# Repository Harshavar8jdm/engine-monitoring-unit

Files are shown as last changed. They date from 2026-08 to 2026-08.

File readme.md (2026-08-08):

# Engine Monitoring Unit (EMU) 🏍️⚡







An open-source, automotive-grade **Engine Monitoring Unit (EMU)** designed to bring real-time engine telemetry and diagnostics to air-cooled single-cylinder motorcycles (such as the Hero Passion Plus) that lack factory instrumentation.

Powered by an **STM32F411CEU6** ARM Cortex-M4 microcontroller, this unit captures vital thermal, electrical, and rotational parameters and displays them on a handlebar-mounted OLED screen—giving riders full visibility over engine health during long highway cruises and touring trips.

---

## 📌 Gallery

| Top 3D Render | Bottom 3D Render |
| :---: | :---: |
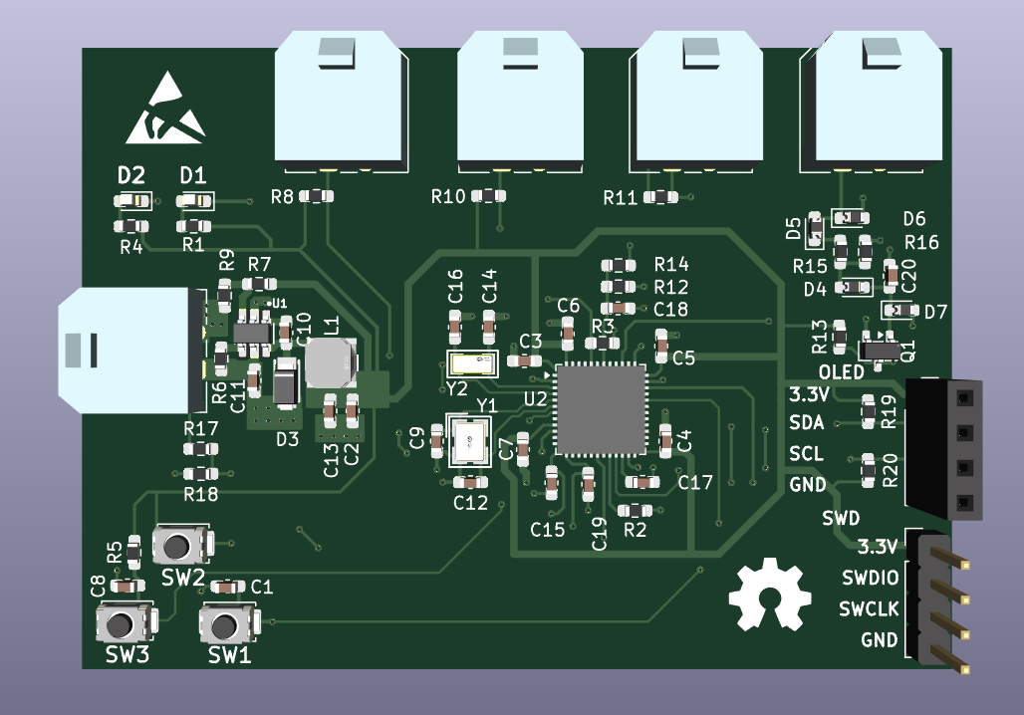
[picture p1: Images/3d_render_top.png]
Top 3D Render
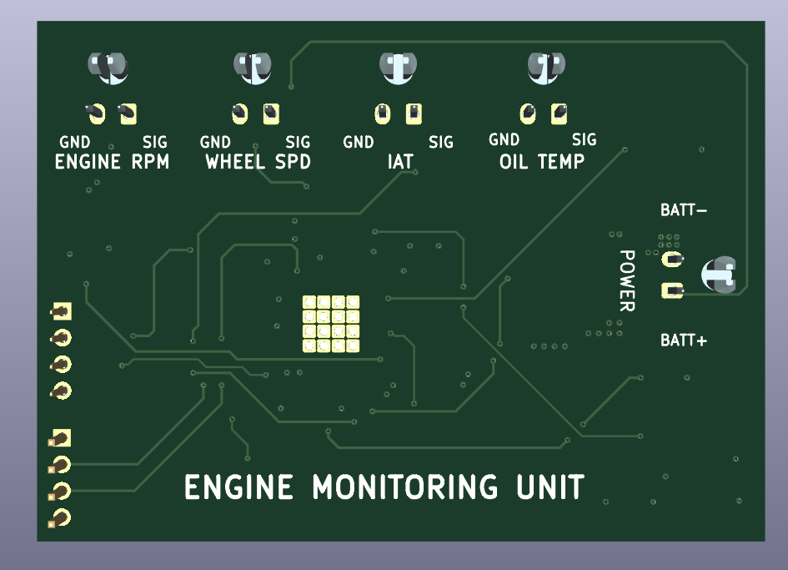
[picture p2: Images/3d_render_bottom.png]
Bottom 3D Render
|  |  |

---

## 🎯 Motivation & Objectives

Stock commuter motorcycles often lack essential monitoring tools, providing only a basic speedometer and fuel gauge. When pushing small-displacement air-cooled engines on long rides or steep climbs, thermal overload or electrical failure can happen without warning.

This project solves that real-world problem by providing:
1. **Real-time Engine Health Visibility:** Monitoring oil temperature and intake air temperature (IAT) to prevent overheating.
2. **Electrical System Telemetry:** Tracking live battery voltage to monitor stator and regulator/rectifier performance.
3. **Engine Dynamics:** Accurate engine RPM via inductive pulse pickup and wheel speed tracking.
4. **Automotive EMI Immunity:** Designed specifically for high noise/vibration motorcycle chassis environments.
5. **Zero Parasitic Battery Drain:** Tied directly to switched ignition (+12V)—completely powered down when the key is OFF.

---

## 🛠️ Key Technical Specifications

| Parameter | Specification | Description |
| :--- | :--- | :--- |
| **Microcontroller** | STM32F411CEU6 | 100 MHz ARM Cortex-M4, 512KB Flash, 128KB SRAM |
| **Operating Voltage** | 12V DC nominal (Switched) | Powered directly from motorcycle ignition bus |
| **On-board Power** | LMR16006 Buck Converter | 12V → 3.3V Step-down (60V Max $V_{IN}$) |
| **Current Draw** | < 0.6A Operating | 0A Off-state (Zero parasitic load) |
| **PCB Stackup** | 4-Layer | Top (Sig/Pwr) - GND - GND - Bottom (Sig) |
| **Connectors** | Molex Micro-Fit 3.0 | Positive-locking, high-vibration automotive rating |
| **Display Interface** | 0.96" I2C OLED | 4-pin header (3.3V, SDA, SCL, GND) |
| **Debug Interface** | SWD | 4-pin header (3.3V, SWDIO, SWCLK, GND) |

---

## 📐 System Architecture & Schematic Overview

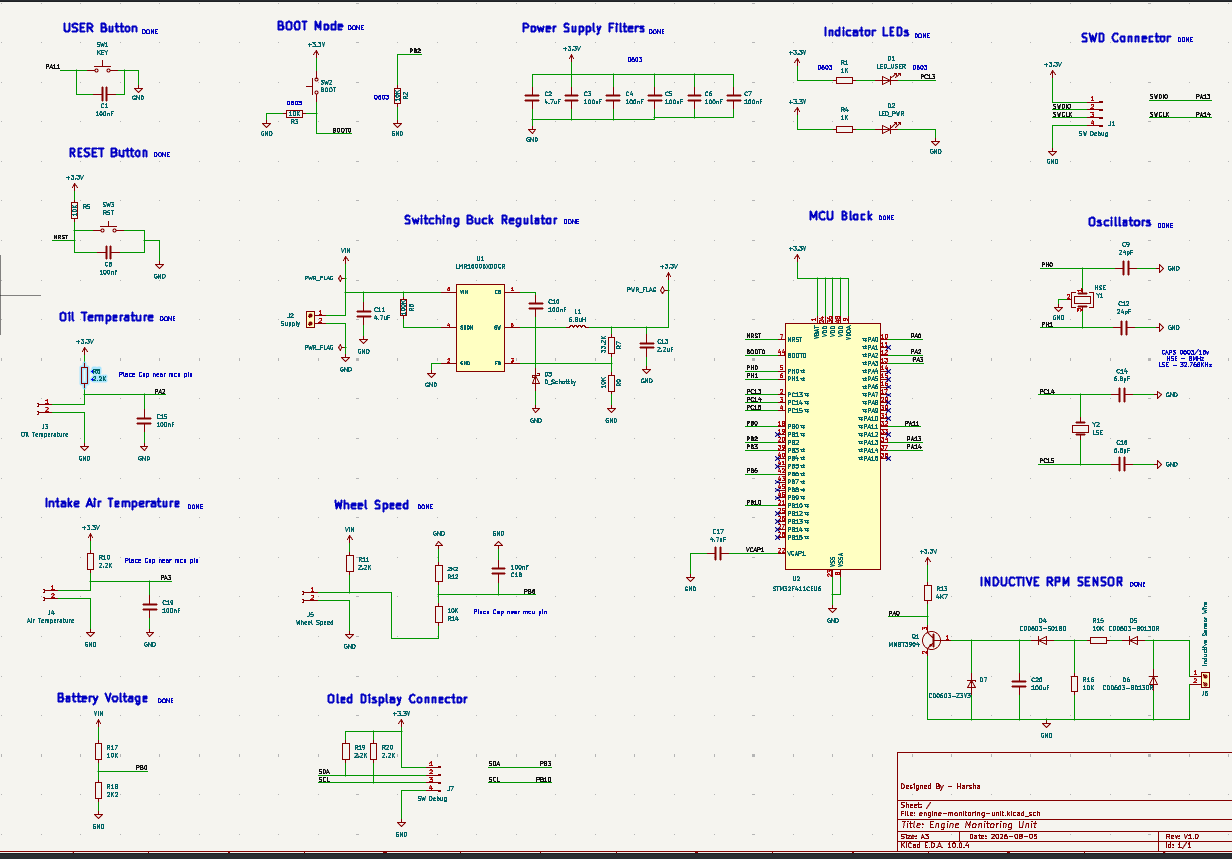
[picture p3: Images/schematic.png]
Full Schematic


### Circuit Block Summary:
* **Power Supply:** Uses a high-efficiency **LMR16006** synchronous buck regulator stepping down battery voltage to $+3.3\text{V}$ for the MCU and OLED display.
* **Microcontroller Core:** Minimalist STM32F411 layout with external $8\text{ MHz}$ HSE crystal ($Y_1$) and $32.768\text{ kHz}$ LSE crystal ($Y_2$), full decoupling capacitor network ($C_2 - C_7$), and pull-up/down logic for BOOT0/NRST.
* **Inductive RPM Conditioning:** Discrete NPN transistor ($Q_1$) amplifier stage paired with high-speed clamping diodes ($D_4 - D_7$) to cleanly condition high-voltage spark-plug coil inductive pulses into a 3.3V digital square wave.
* **Analog Sensor Inputs:** Resistive voltage dividers and $100\text{ nF}$ filtering capacitors for Oil Temp ($J_3$), Intake Air Temp ($J_4$), and Battery Voltage sensing ($J_2$).
* **Wheel Speed Conditioning:** Digital pulse input circuit with pull-up and low-pass filtering for hall-effect or reed switch wheel sensors ($J_5$).

---

## 📑 PCB Stackup & Layer Breakdown

To withstand the severe Electromagnetic Interference (EMI) generated by motorcycle ignition coils and spark plugs, the PCB utilizes a dedicated **4-layer stackup** with dual continuous internal ground planes.

```text
┌─────────────────────────────────────────────────────────┐
│ Layer 1: Top Layer (FCU)    -> Signals + 3.3V Power     │
├─────────────────────────────────────────────────────────┤
│ Layer 2: Inner 1 (In1)      -> Solid Ground Plane (GND) │
├─────────────────────────────────────────────────────────┤
│ Layer 3: Inner 2 (In2)      -> Solid Ground Plane (GND) │
├─────────────────────────────────────────────────────────┤
│ Layer 4: Bottom Layer (BCU) -> Signal Routing           │
└─────────────────────────────────────────────────────────┘

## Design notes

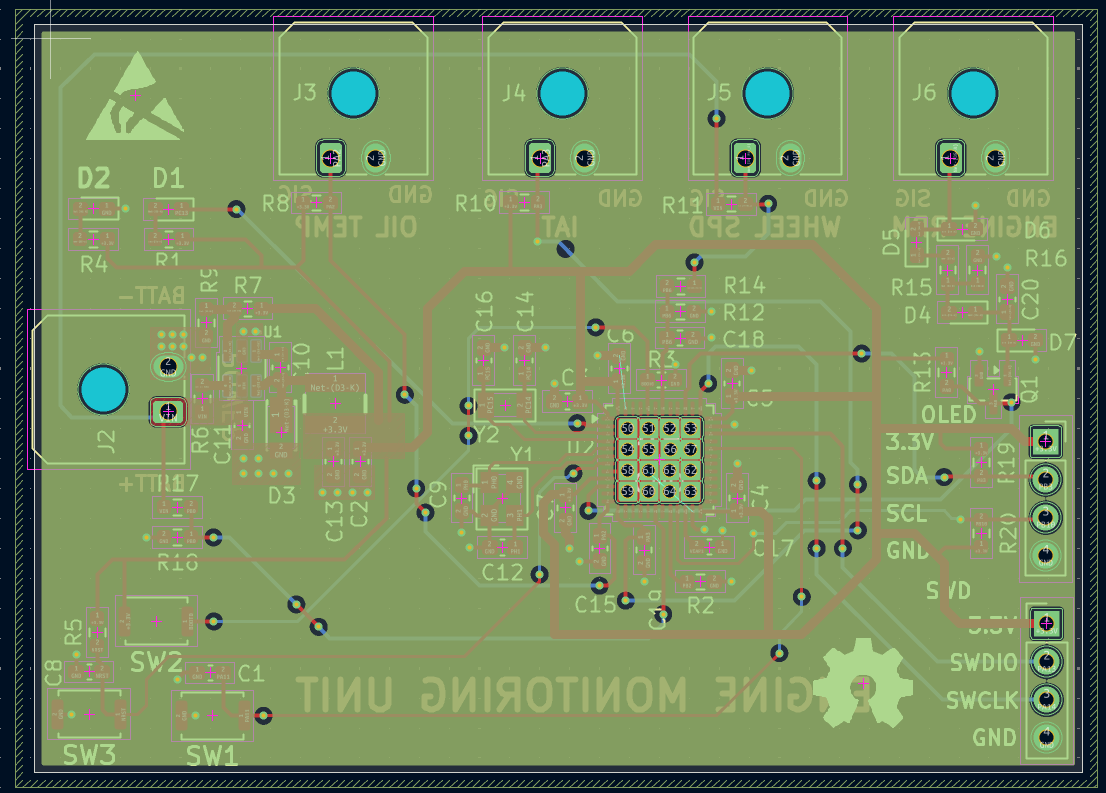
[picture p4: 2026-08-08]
Images/pcb_layout_in1.png

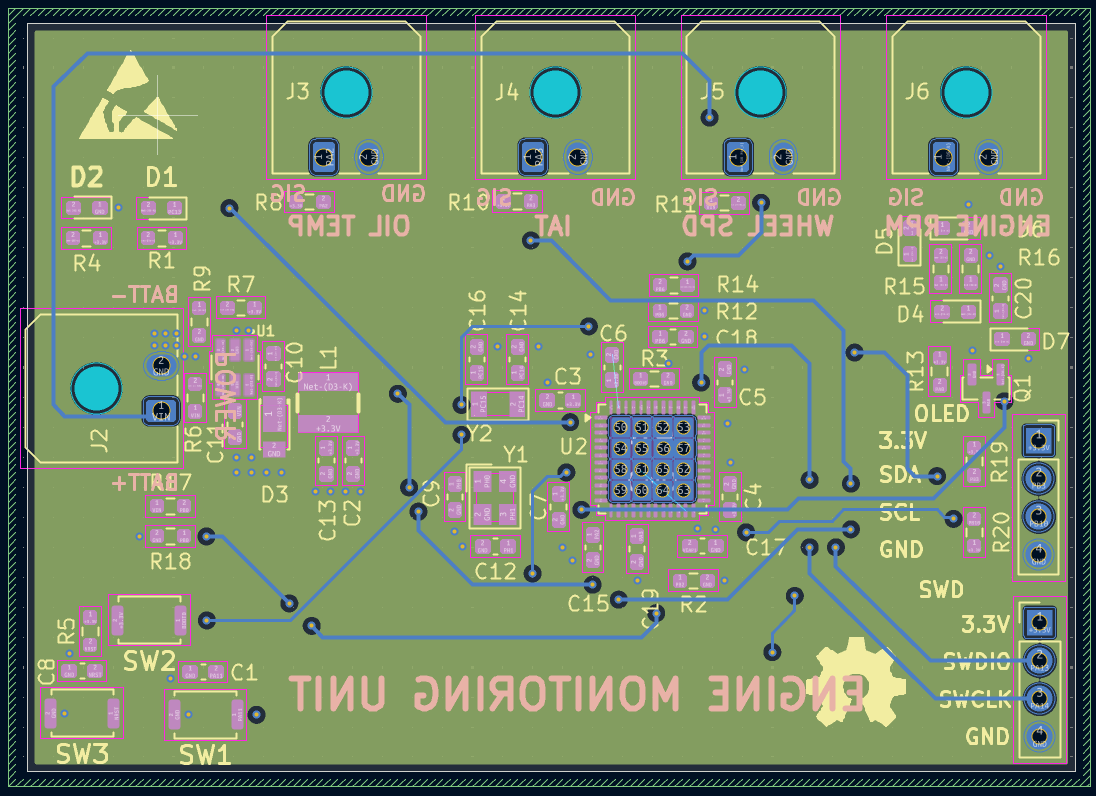
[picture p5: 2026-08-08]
Images/pcb_layout_bcu.png

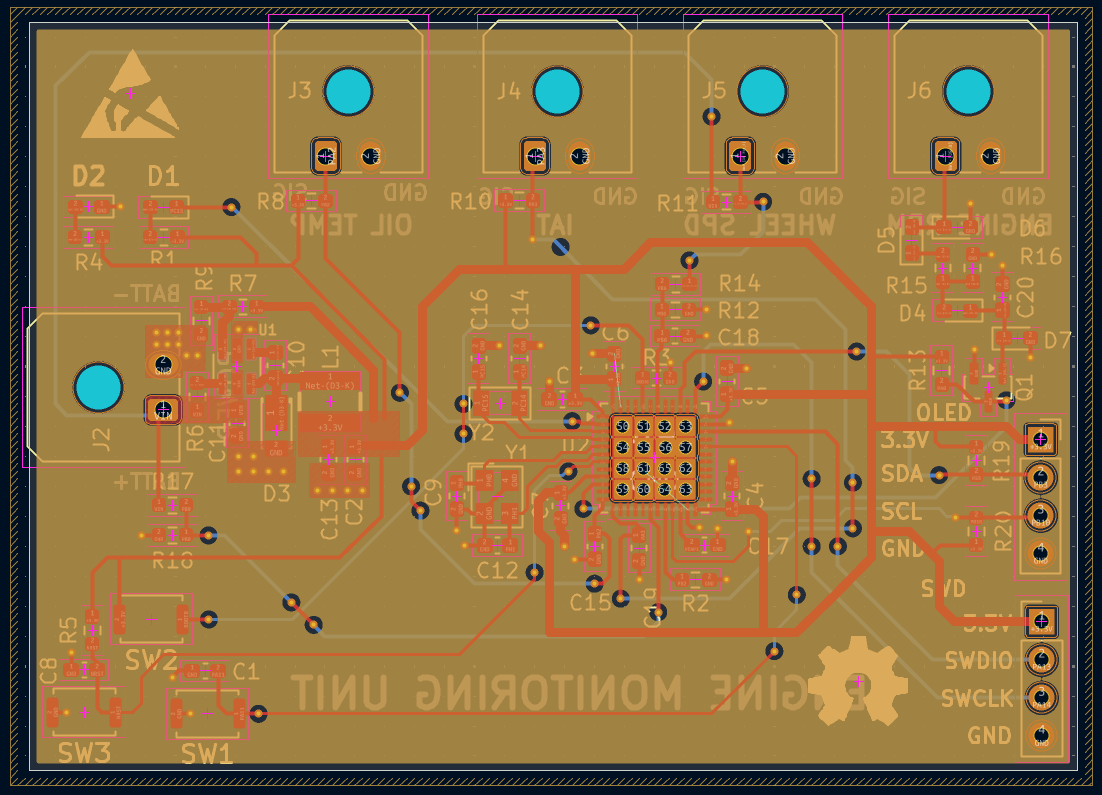
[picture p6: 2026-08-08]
Images/pcb_layout_in2.png

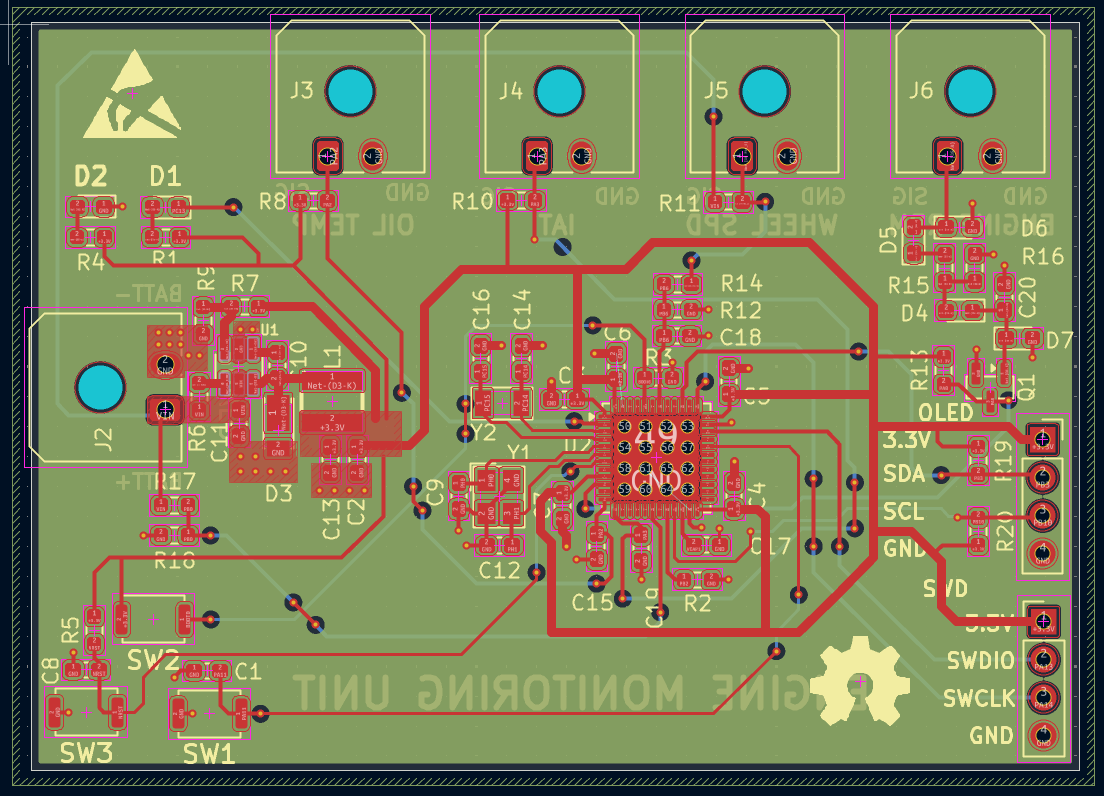
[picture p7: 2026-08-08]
Images/pcb_layout_fcu.png

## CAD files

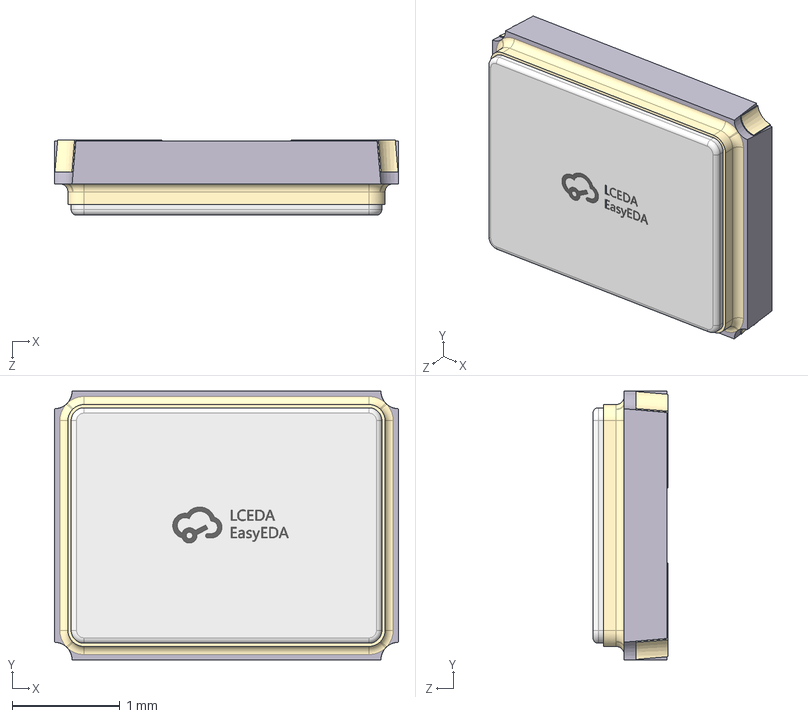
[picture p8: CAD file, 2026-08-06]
ext-libs/hse/CRYSTAL-SMD_4P-L3_2-W2_5-BL_0132M4-8_000F16DTNJL_C19674293/CRYSTAL-SMD_4P-L3_2-W2_5-BL_0132M4-8_000F16DTNJL_C19674293.step
3.20 x 2.50 x 0.701 mm

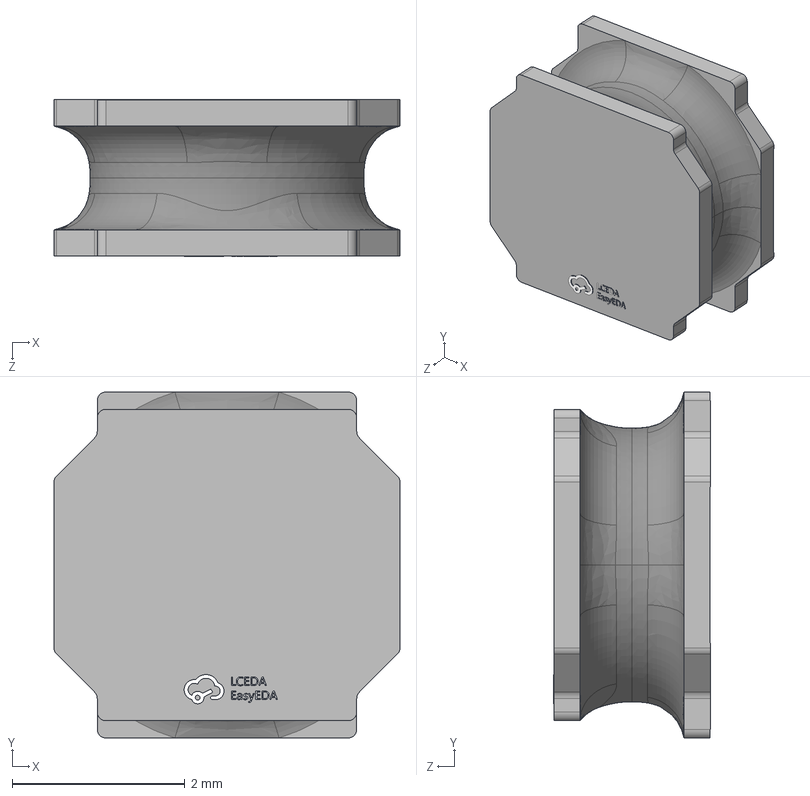
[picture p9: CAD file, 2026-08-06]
ext-libs/Inductor-6.8uH/IND-SMD_L4_0-W4_0_NRS4018T_NRS4018T6R8MDGJ_C222881.step
4.00 x 4.00 x 1.82 mm

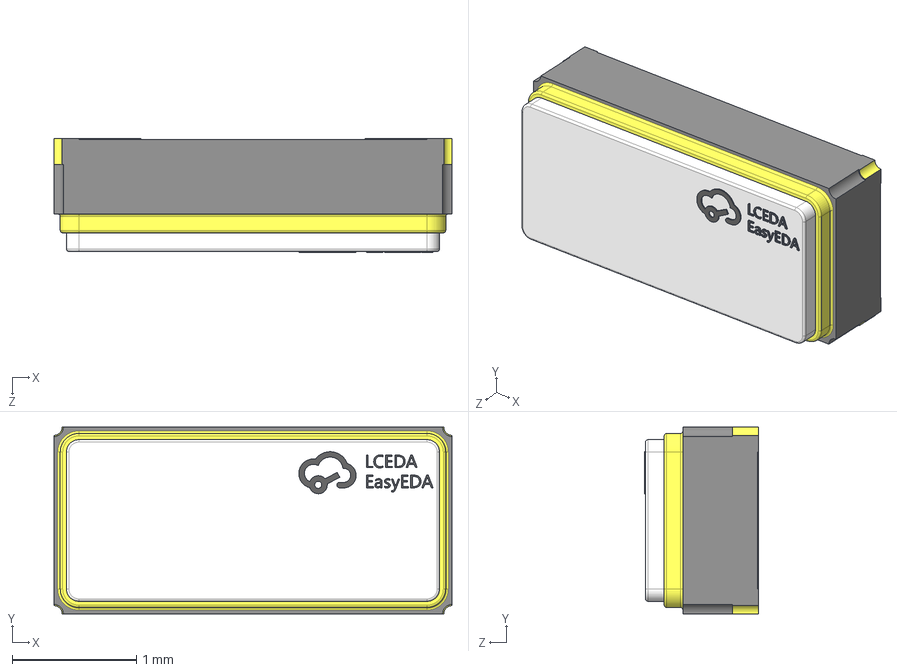
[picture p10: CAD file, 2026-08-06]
ext-libs/lse/CRYSTAL-SMD_L3_2-W1_5-1_3131M32768DT06LL_C5221300.step
3.20 x 1.50 x 0.92 mm

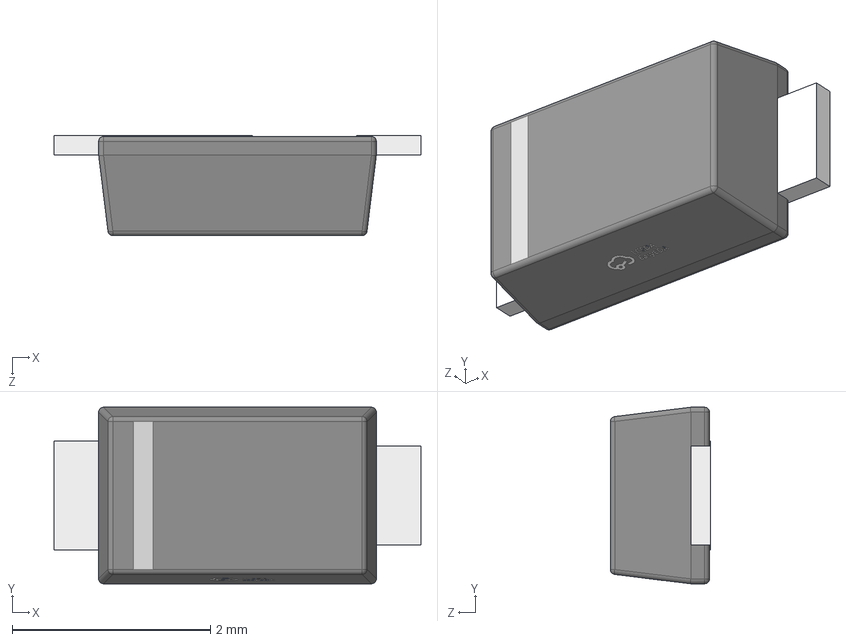
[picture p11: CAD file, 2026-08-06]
ext-libs/Schottky/POWERDI-123_L2_8-W1_8-LS3_7-RD-1_SS14FP_C894423.step
3.70 x 1.78 x 1.01 mm

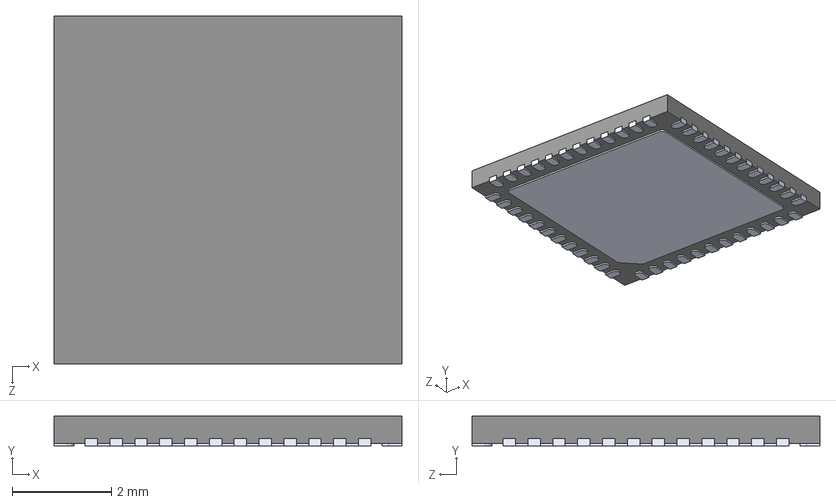
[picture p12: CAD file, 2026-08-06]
ext-libs/STM32F411CEU6/STM32F411CEU6TR.STEP
7.00 x 0.6 x 7.00 mm

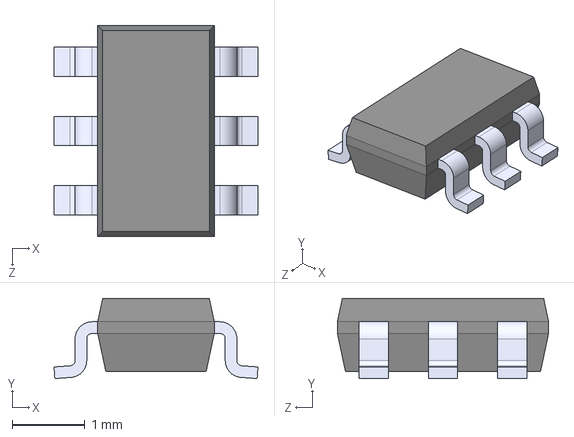
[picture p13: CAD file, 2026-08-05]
ext-libs/LMR16006XDDCR/LMR16006XDDCR.step
2.80 x 1.10 x 2.90 mm

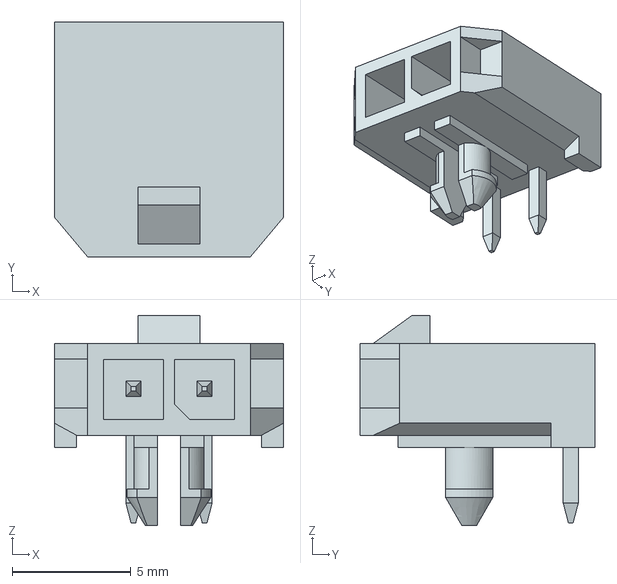
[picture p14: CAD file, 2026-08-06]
ext-libs/MOLEX_Micro-Fit-3-2P/436500200.stp
9.65 x 9.90 x 8.87 mm

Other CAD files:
ext-libs/Inductor-6.8uH/IND-SMD_L4_0-W4_0_NRS4018T_NRS4018T6R8MDGJ_C222881.obj
ext-libs/Schottky/POWERDI-123_L2_8-W1_8-LS3_7-RD-1_SS14FP_C894423.obj
ext-libs/hse/CRYSTAL-SMD_4P-L3_2-W2_5-BL_0132M4-8_000F16DTNJL_C19674293/CRYSTAL-SMD_4P-L3_2-W2_5-BL_0132M4-8_000F16DTNJL_C19674293.obj
ext-libs/lse/CRYSTAL-SMD_L3_2-W1_5-1_3131M32768DT06LL_C5221300.obj

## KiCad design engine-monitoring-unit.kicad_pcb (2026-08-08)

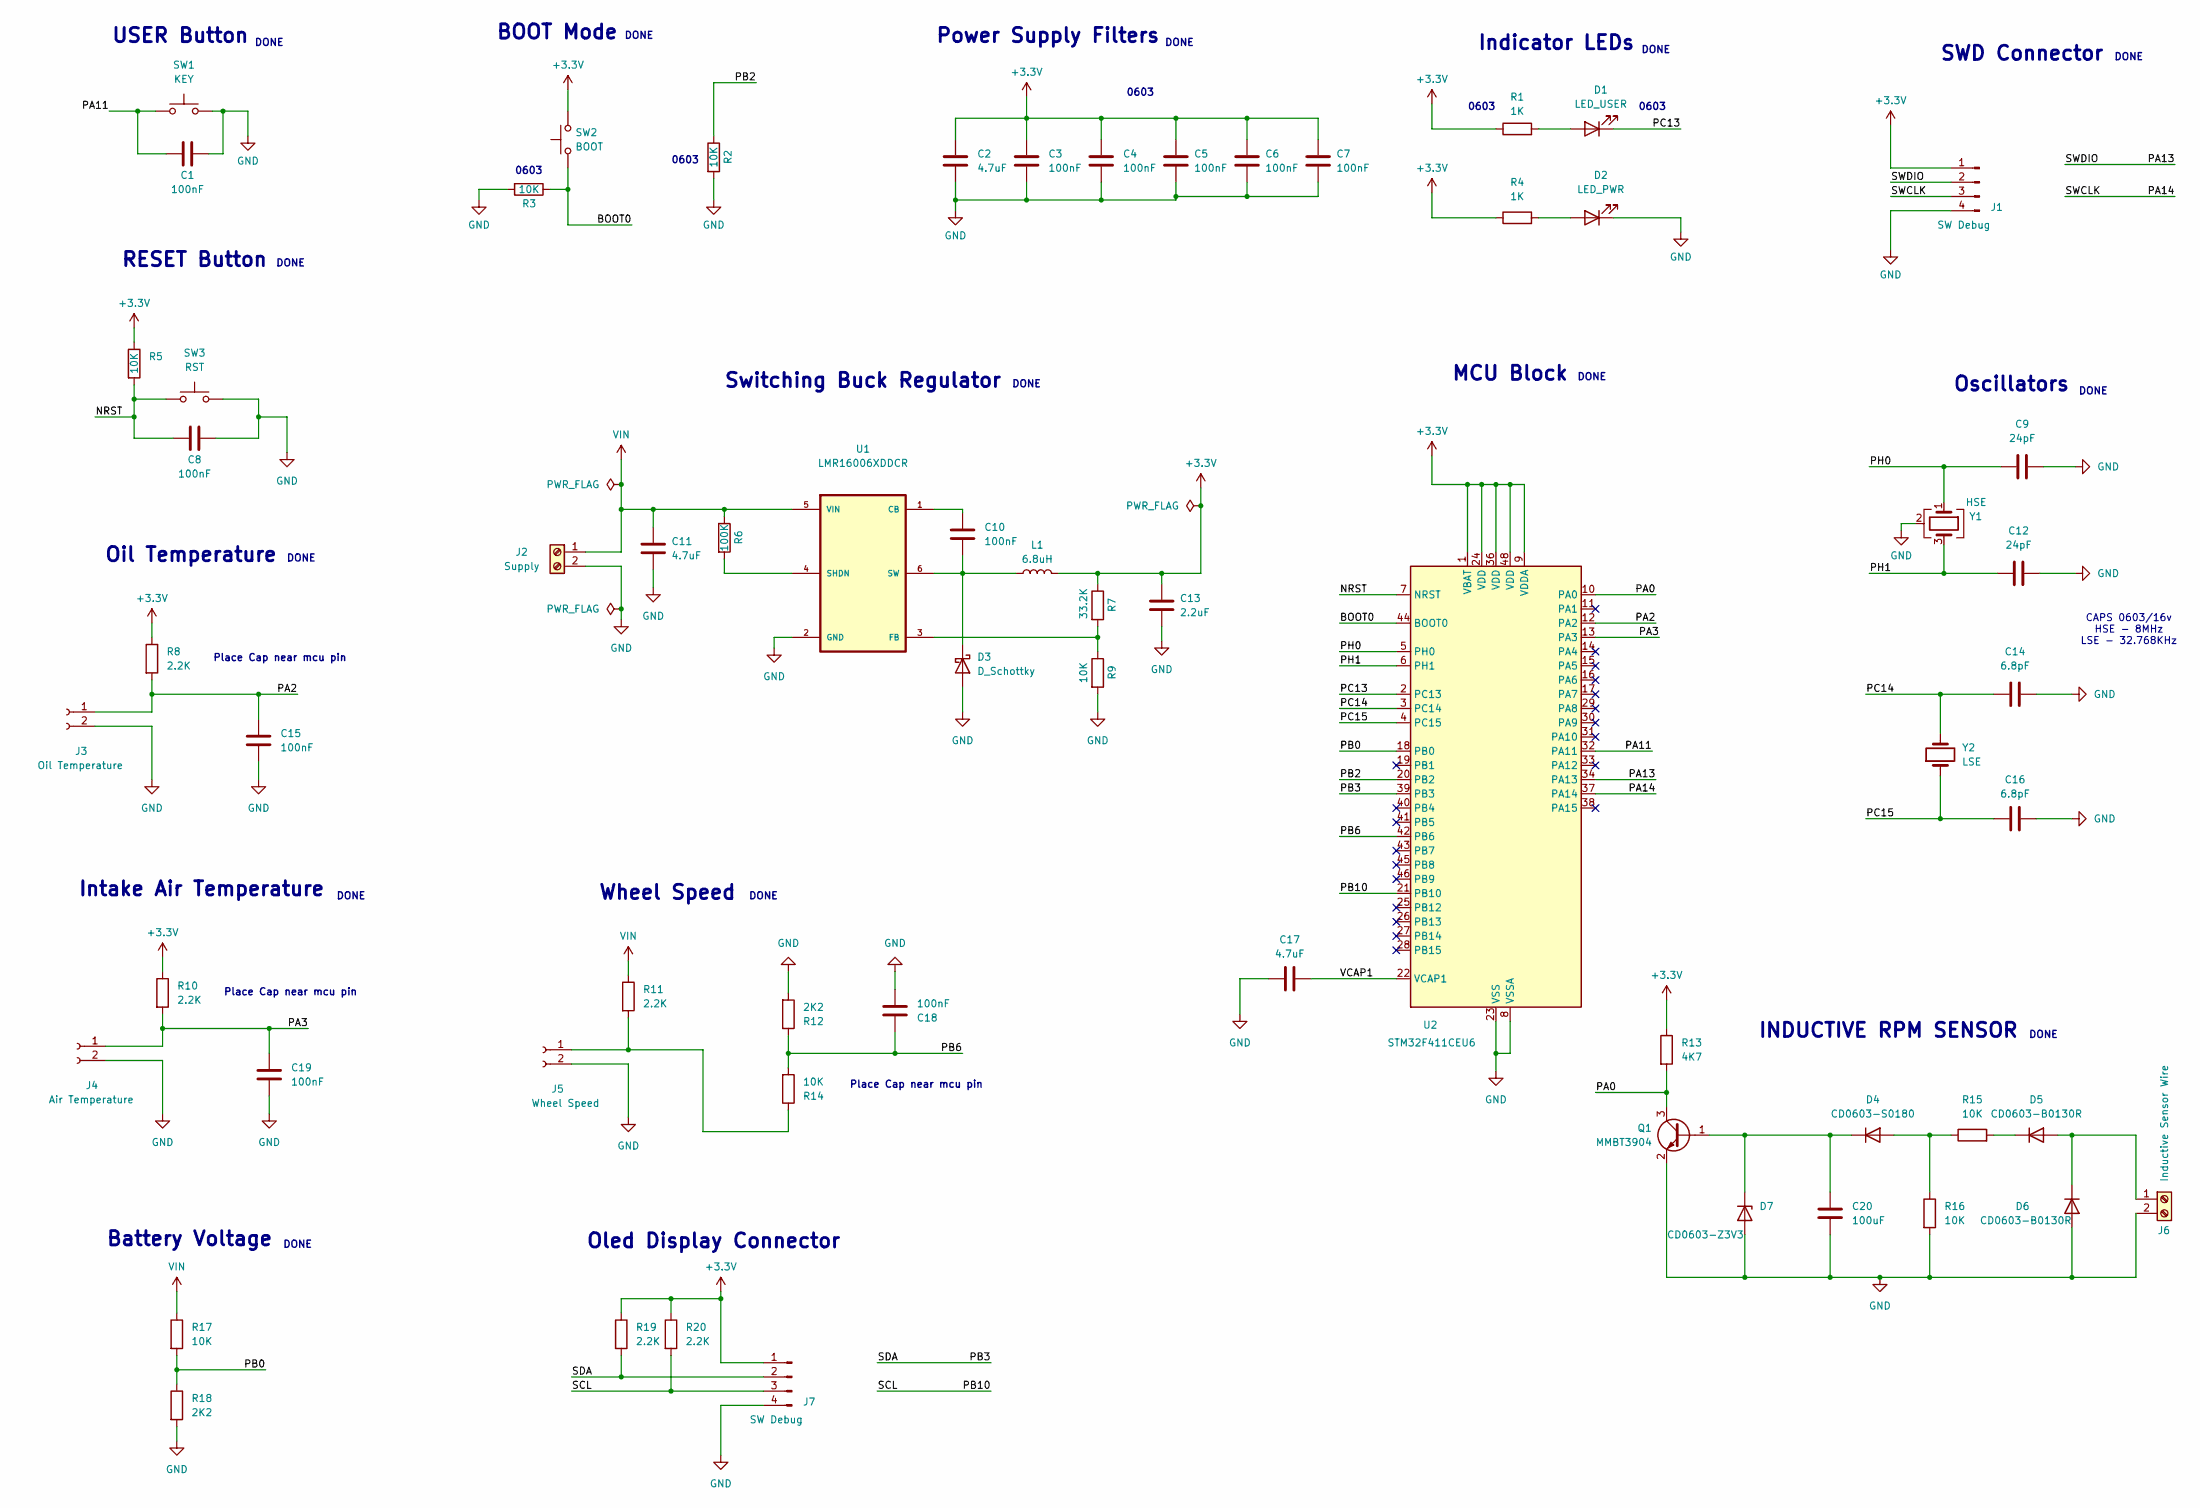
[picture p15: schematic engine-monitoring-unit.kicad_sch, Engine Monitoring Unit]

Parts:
C1, C3, C4, C5, C6, C7, C8, C10, C15, C18, C19: 100nF; C_0603_1608Metric_Pad1.08x0.95mm_HandSolder
C2, C11, C17: 4.7uF; C_0603_1608Metric_Pad1.08x0.95mm_HandSolder
C9, C12: 24pF; C_0603_1608Metric_Pad1.08x0.95mm_HandSolder
C13: 2.2uF; C_0603_1608Metric_Pad1.08x0.95mm_HandSolder
C14, C16: 6.8pF; C_0603_1608Metric_Pad1.08x0.95mm_HandSolder
C20: 100uF; C_0603_1608Metric_Pad1.08x0.95mm_HandSolder
D1: LED_USER; LED_0603_1608Metric_Pad1.05x0.95mm_HandSolder
D2: LED_PWR; LED_0603_1608Metric_Pad1.05x0.95mm_HandSolder
D3: D_Schottky; POWERDI-123_L2_8-W1_8-LS3_7-RD-1_SS14FP_C894423
D4: CD0603-S0180; D_0603_1608Metric_Pad1.05x0.95mm_HandSolder
D5, D6: CD0603-B0130R; D_0603_1608Metric_Pad1.05x0.95mm_HandSolder
D7: CD0603-Z3V3; D_0603_1608Metric_Pad1.05x0.95mm_HandSolder
J1: SW Debug; PinHeader_1x04_P2.54mm_Vertical
J2: Supply; Molex_Micro-Fit_3.0_43650-0200_1x02_P3.00mm_Horizontal
J3: Oil Temperature; Molex_Micro-Fit_3.0_43650-0200_1x02_P3.00mm_Horizontal
J4: Air Temperature; Molex_Micro-Fit_3.0_43650-0200_1x02_P3.00mm_Horizontal
J5: Wheel Speed; Molex_Micro-Fit_3.0_43650-0200_1x02_P3.00mm_Horizontal
J6: Inductive Sensor Wire; Molex_Micro-Fit_3.0_43650-0200_1x02_P3.00mm_Horizontal
J7: SW Debug; PinSocket_1x04_P2.54mm_Vertical
L1: 6.8uH; IND-SMD_L4_0-W4_0_NRS4018T_NRS4018T6R8MDGJ_C222881
Q1: MMBT3904; SOT-23
R1, R4: 1K; R_0603_1608Metric_Pad0.98x0.95mm_HandSolder
R2, R3, R5, R9, R14, R15, R16, R17: 10K; R_0603_1608Metric_Pad0.98x0.95mm_HandSolder
R6: 100K; R_0603_1608Metric_Pad0.98x0.95mm_HandSolder
R7: 33.2K; R_0603_1608Metric_Pad0.98x0.95mm_HandSolder
R8, R10, R11, R19, R20: 2.2K; R_0603_1608Metric_Pad0.98x0.95mm_HandSolder
R12, R18: 2K2; R_0603_1608Metric_Pad0.98x0.95mm_HandSolder
R13: 4K7; R_0603_1608Metric_Pad0.98x0.95mm_HandSolder
SW1: KEY; SW_Push_SPST_NO_Alps_SKRK
SW2: BOOT; SW_Push_SPST_NO_Alps_SKRK
SW3: RST; SW_Push_SPST_NO_Alps_SKRK
U1: LMR16006XDDCR; SOT95P280X110-6N
U2: STM32F411CEU6; QFN-48-1EP_7x7mm_P0.5mm_EP5.6x5.6mm
Y1: HSE; CRYSTAL-SMD_4P-L3_2-W2_5-BL_0132M4-8_000F16DTNJL_C19674293
Y2: LSE; CRYSTAL-SMD_L3_2-W1_5-1_3131M32768DT06LL_C5221300

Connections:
+3.3V: C2.1, C3.1, C4.1, C5.1, C6.1, C7.1, C13.1, J1.1, J7.1, L1.2, R1.1, R4.1, R5.1, R7.1, R8.1, R10.1, R13.1, R19.1, R20.1, SW2.2, U2.1 (VBAT), U2.9 (VDDA), U2.24 (VDD), U2.36 (VDD), U2.48 (VDD)
/BOOT0: R3.1, SW2.1, U2.44 (BOOT0)
/NRST: C8.2, R5.2, SW3.1, U2.7 (NRST)
/PA0: Q1.3 (C), R13.2, U2.10 (PA0)
/PA2: C15.1, J3.1, R8.2, U2.12 (PA2)
/PA3: C19.1, J4.1, R10.2, U2.13 (PA3)
/PA11: C1.2, SW1.1, U2.32 (PA11)
/PA13: J1.2, U2.34 (PA13)
/PA14: J1.3, U2.37 (PA14)
/PB0: R17.2, R18.1, U2.18 (PB0)
/PB2: R2.1, U2.20 (PB2)
/PB3: J7.2, R19.2, U2.39 (PB3)
/PB6: C18.1, R12.1, R14.2, U2.42 (PB6)
/PB10: J7.3, R20.2, U2.21 (PB10)
/PC13: D1.1 (K), U2.2 (PC13)
/PC14: C14.1, U2.3 (PC14), Y2.2
/PC15: C16.1, U2.4 (PC15), Y2.1
/PH0: C9.1, U2.5 (PH0), Y1.1
/PH1: C12.1, U2.6 (PH1), Y1.3
/VCAP1: C17.2, U2.22 (VCAP1)
GND: C1.1, C2.2, C3.2, C4.2, C5.2, C6.2, C7.2, C8.1, C9.2, C11.2, C12.2, C13.2, C14.2, C15.2, C16.2, C17.1, C18.2, C19.2, C20.2, D2.1 (K), D3.2 (A), D6.2 (A), D7.2 (A), J1.4, J2.2, J3.2, J4.2, J5.2, J6.2, J7.4, Q1.2 (E), R2.2, R3.2, R9.2, R12.2, R16.2, R18.2, SW1.2, SW3.2, U1.2 (GND), U2.8 (VSSA), U2.23 (VSS), U2.35 (VSS), U2.47 (VSS), U2.49 (VSS), Y1.2 (G), Y1.4 (G)
unnamed: D1.2 (A), R1.2
unnamed: D2.2 (A), R4.2
unnamed: C10.2, D3.1 (K), L1.1, U1.6 (SW)
unnamed: D4.2 (A), R15.1, R16.1
unnamed: C20.1, D4.1 (K), D7.1 (K), Q1.1 (B)
unnamed: D5.2 (A), D6.1 (K), J6.1
unnamed: D5.1 (K), R15.2
unnamed: J5.1, R11.2, R14.1
unnamed: C10.1, U1.1 (CB)
unnamed: R7.2, R9.1, U1.3 (FB)
unnamed: R6.2, U1.4 (SHDN)
VIN: C11.1, J2.1, R6.1, R11.1, R17.1, U1.5 (VIN)

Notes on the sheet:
Indicator LEDs
Place Cap near mcu pin
DONE
Battery Voltage
INDUCTIVE RPM SENSOR
CAPS 0603/16v HSE - 8MHz LSE - 32.768KHz
SWD Connector
Intake Air Temperature
Power Supply Filters
Oil Temperature
0603
Oscillators
USER Button
BOOT Mode
Switching Buck Regulator
Wheel Speed
Oled Display Connector
MCU Block
RESET Button

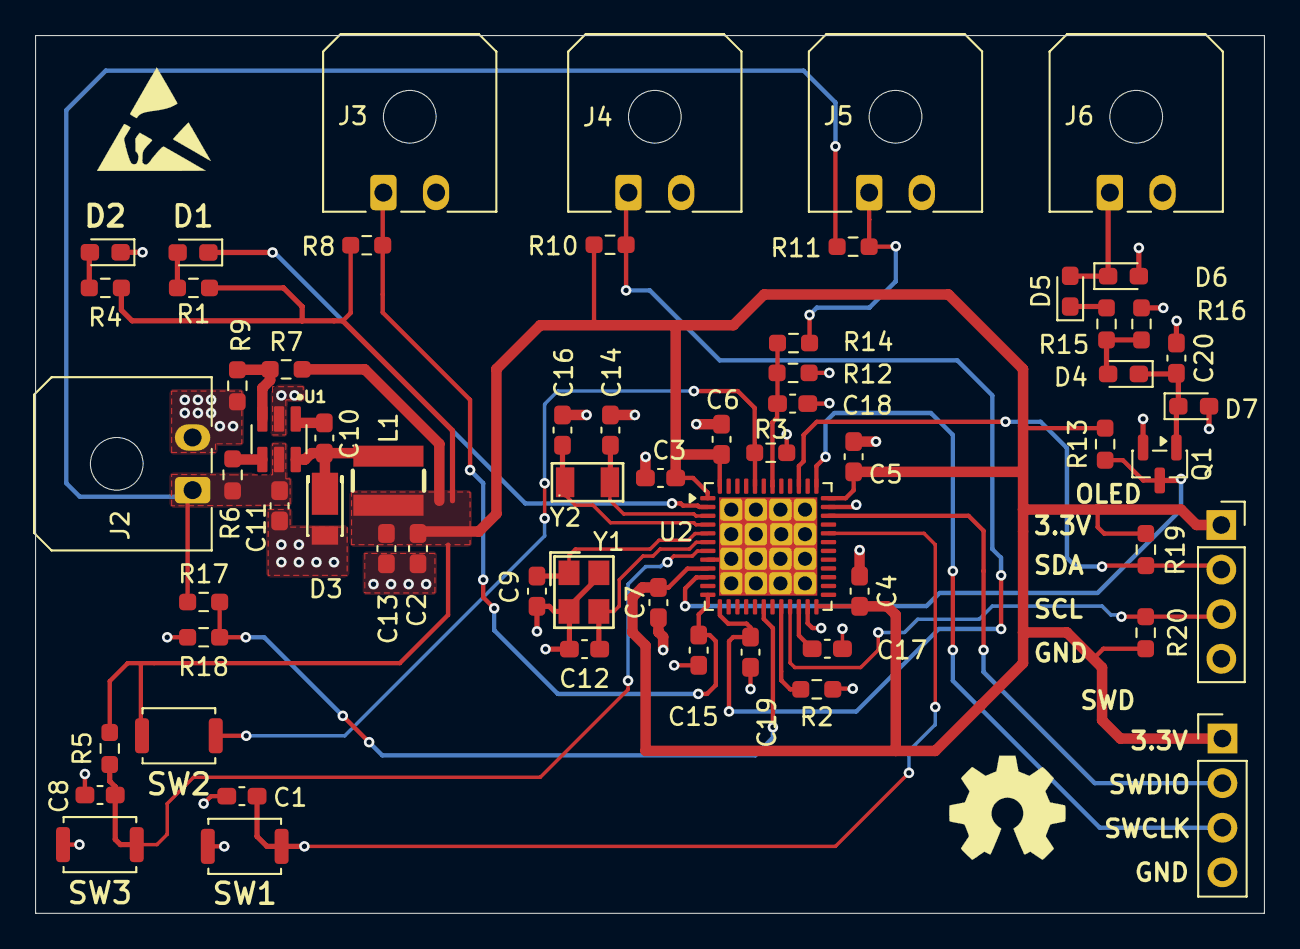
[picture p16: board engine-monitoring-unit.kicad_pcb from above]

Board: 4 copper layers, 70.0 x 50.0 mm, 63 parts (0 on the bottom side), 33 nets.

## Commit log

2026-08-05 Assigned Footprints for components
    [engine-monitoring-unit.kicad_sch]
2026-08-06 Assigned 3D Models for missing ones
    [436500200.stp, CRYSTAL-SMD_4P-L3_2-W2_5-BL_0132M4-8_000F16DTNJL_C19674293.obj, CRYSTAL-SMD_4P-L3_2-W2_5-BL_0132M4-8_000F16DTNJL_C19674293.step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]
2026-08-06 Updated Page Settings, Board Stackup and Constraints
    [engine-monitoring-unit.kicad_pcb, engine-monitoring-unit.kicad_sch]
2026-08-06 Layed out regulator circuit
    [engine-monitoring-unit.kicad_pcb]
2026-08-06 Layed out decoupling caps, connectors and switches
    [engine-monitoring-unit.kicad_pcb, engine-monitoring-unit.kicad_sch]
2026-08-06 Fixed Schematic Errors
    [engine-monitoring-unit.kicad_pcb]
2026-08-08 Routed Signal Traces
    [engine-monitoring-unit.kicad_pcb, engine-monitoring-unit.kicad_sch]
2026-08-08 Ground Vias
2026-08-08 Updated Footprint for swd
    [engine-monitoring-unit.kicad_pcb, engine-monitoring-unit.kicad_sch]
2026-08-08 Updated Silkscreen
    [engine-monitoring-unit.kicad_pcb]
2026-08-08 Added Silkscreen Detaisls
    [engine-monitoring-unit.kicad_pcb]
2026-08-08 Added Silkscreen Details
    [engine-monitoring-unit.kicad_pcb]
2026-08-08 Added OLED Display Socket
    [engine-monitoring-unit.kicad_pcb, engine-monitoring-unit.kicad_sch]
2026-08-08 Silkscreen Updated
2026-08-08 Modified Layout
    [engine-monitoring-unit.kicad_pcb]
2026-08-08 Updated Media
    [engine-monitoring-unit.kicad_pcb]

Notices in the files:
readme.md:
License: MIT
